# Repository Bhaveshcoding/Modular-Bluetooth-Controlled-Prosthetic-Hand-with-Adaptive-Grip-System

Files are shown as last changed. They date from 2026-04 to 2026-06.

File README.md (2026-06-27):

# Bluetooth-Controlled Prosthetic Hand

---

# NOTE

This project was originally started for Stasis and is now being transferred to Horizons with permission from both organizers.

No funding was received from Stasis, and the project was never approved there. Since Stasis does not require the use of Lapse, I kindly request that project hours be evaluated based on my submitted journal entries.

P.S.-PERMISSION WAS TAKEN FROM @phthallo FOR DOING IT THIS WAY.

Thank you for your consideration.

---

# What It Is

This is a Bluetooth-controlled prosthetic hand that uses servo motors and a simple tendon-driven mechanism to move the fingers. The hand is controlled using an HC-05 Bluetooth module and an Arduino Uno.

I designed all of the CAD myself and built the electronics around it. The goal wasn't to make a medical-grade prosthetic, but to understand how prosthetic hands work and build a working prototype from scratch.

---

## Why I Made This

I've always found prosthetics and assistive technology interesting, so I wanted to try building one myself.

This project gave me a chance to learn more about CAD, mechanical design, electronics, servo control, and how tendon-driven systems work. It also helped me understand some of the challenges involved in designing devices that assist people in everyday tasks.

The project is fairly simple, but it taught me a lot and was a fun way to combine mechanical and electrical design into one build.

---

## CAD

### NOTE

Arm + Electronics Assembly - [(.7z Archive)](CAD/Arm+electronics.7z)

Contains the mandatory **.STEP** file with the complete assembly and integrated electronics. The archive is compressed because of its size.

Google Drive Link:

https://drive.google.com/file/d/1kVEwLl6yhaGHvDUCItGak4jiyQgdJik9/view?usp=sharing

#### STEP Format Files

```text
CAD/3D%20Files%20Robo%20Hand
```

#### F3D & F3Z Format Files

```text
CAD/ROBO%20hand%20files(f3d)
```

## CAD of the Project

#### Full CAD Model

```text
CAD\ROBO hand files(f3d)\hand_3D_RENDER.f3z
```
### Picture of the 3D Printed Model

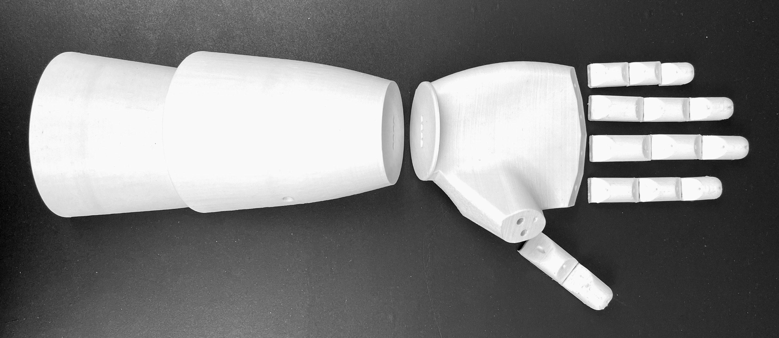
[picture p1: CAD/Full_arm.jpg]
3D printed arm Model


---

### CAD Render

Full CAD Model

---

### Another View

Side View

---

## Design

### Finger Design

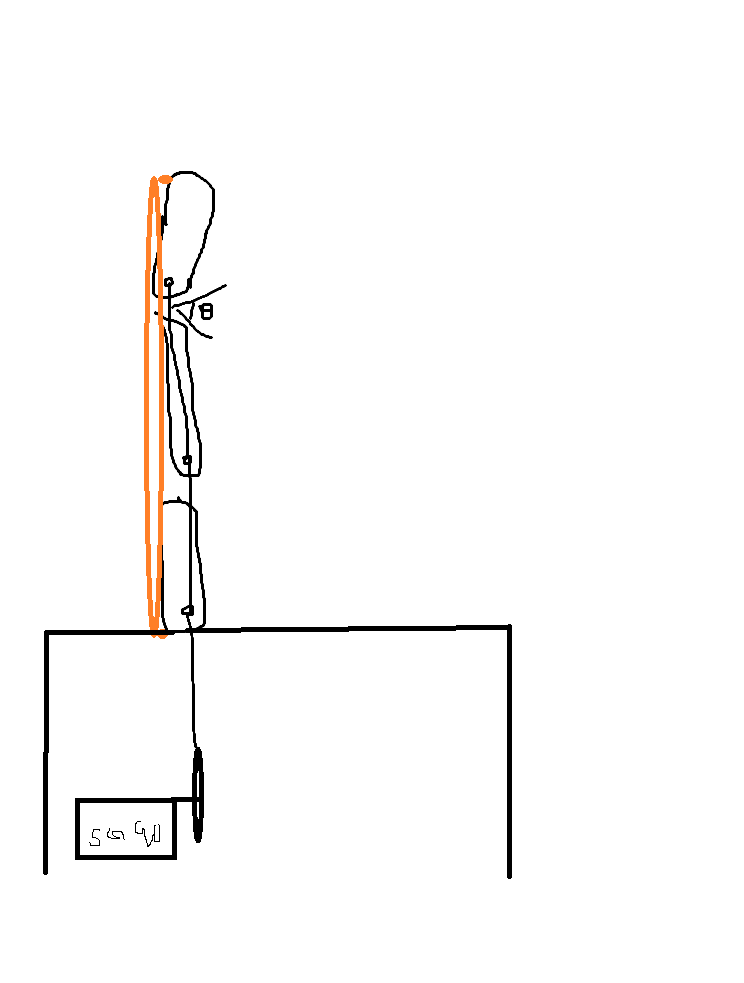
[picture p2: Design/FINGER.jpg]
Finger design


---

### Full Hand Design

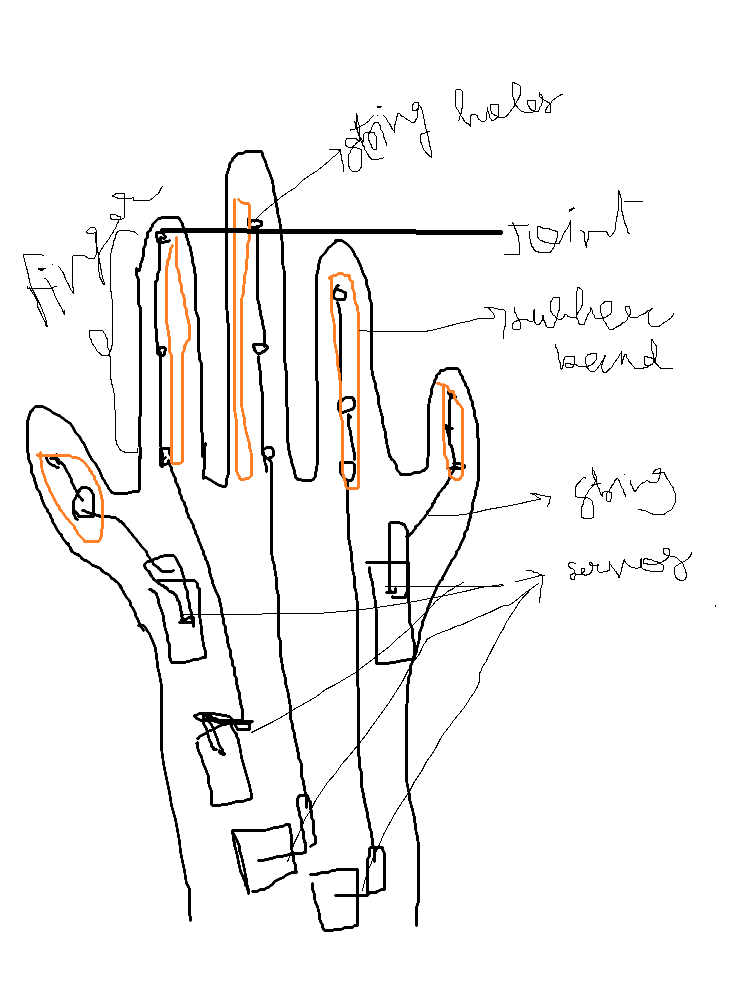
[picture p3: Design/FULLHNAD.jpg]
Full Hand design


---

# Electronics

### TinkerCAD Circuit

https://www.tinkercad.com/things/5ojhNEz72F2-circuit-prosthetichand/editel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

---

### Wiring Diagram

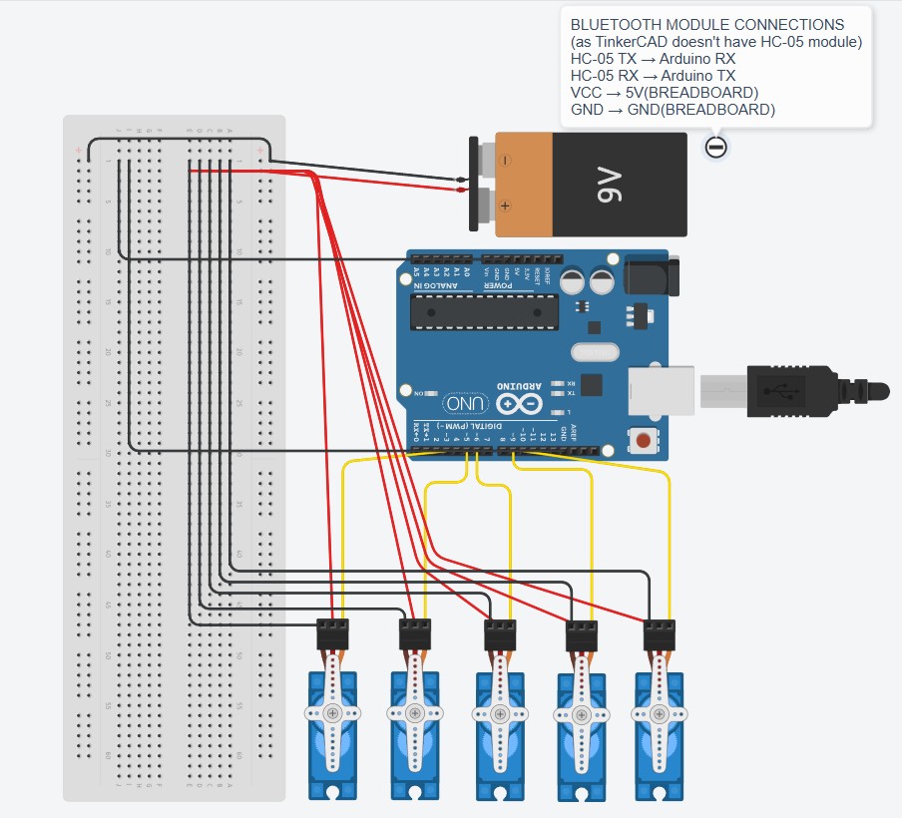
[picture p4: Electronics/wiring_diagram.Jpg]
Wiring Diagram


---

### TinkerCAD Simulation

TinkerCAD Setup

---

I didn't design a PCB for this version of the project. Everything was first prototyped on a breadboard so that testing and changes could be made easily.

---

## Main Components

* Arduino UNO R3
* 5 × SG90/MG90S Servo Motors
* HC-05 Bluetooth Module
* 18650 Battery Pack
* Breadboard
* Jumper Wires
* Nylon Thread (Tendon Mechanism)
* Elastic Thread (Finger Return Mechanism)

---

## Wiring

### Servo Connections

* D3 → Servo 1
* D5 → Servo 2
* D6 → Servo 3
* D9 → Servo 4
* D10 → Servo 5

### Bluetooth Connections

* HC-05 TX → Arduino RX
* HC-05 RX → Arduino TX

### Power

* External battery pack → Servo power
* Common ground shared between all components

---

# Firmware

The firmware allows the hand to perform a few preset grip patterns as well as individual finger control.

Firmware:

[Firmware](Firmware/hand_control.ino)

---

## Grip Modes

* **O** → Open Hand
* **P** → Power Grip
* **I** → Pinch Grip
* **H** → Partial Grip

---

## Individual Finger Control

* **A / a** → Open / Close Finger 1
* **B / b** → Open / Close Finger 2
* **C / c** → Open / Close Finger 3
* **D / d** → Open / Close Finger 4
* **E / e** → Open / Close Finger 5

To make the movement look less jerky, the servos move gradually instead of jumping directly between positions.
# Files Included

* `/CAD` → STEP, F3D, and F3Z CAD files
* `/Firmware` → Arduino source code
* `/Electronics` → Wiring diagrams and TinkerCAD files
* `/Design` → Design images and references
* `BOM.csv` → Complete bill of materials

---

# Bill of Materials (BOM)

| Name | Purpose | Quantity | Total Cost (USD) | Link | Distributor |
| --- | --- | --- | --- | --- | --- |
| Loctite Super Glue Power Gel | Joining 3D-printed parts | 1 | 4.00 | https://www.amazon.in/Loctite-Flexible-Superglue-Non-Drip-Applications/dp/B001C42J9I | AMAZON |
| 3D Printing Material (PLA/ABS) | Printing the hand components | 1 | 4.00 | https://almightyfila.com/product/pla-3d-printing-filament/ | ALMIGHTY FILA |
| Screws & Fasteners | Mechanical assembly | 6 | 0.50 | https://robu.in/product/easymech-ss-304-csk-countersunk-philips-head-m2-5-x-6-mm-bolt-25-pcs-2/ | ROBU |
| Nylon Thread | Tendon mechanism | 1 | 2.00 | https://www.meesho.com/ultra-thin-strong-bright-nylon-high-tensile-strength-thread | MEESHO |
| Elastic Thread 2mm | Finger return mechanism | 1 | 1.00 | https://www.meesho.com/elastic-band-cord-2mm | MEESHO |
| Breadboard | Circuit prototyping | 1 | 0.50 | https://robocraze.com/products/half-breadboard | ROBOCRAZE |
| Jumper Wires (M-M & M-F) | Electrical connections | 20 | 0.50 | https://robocraze.com/products/f2m-jumper-wires-20cm-40pcs | ROBOCRAZE |
| 3.7V 2900mAh 18650 Battery | Power source | 2 | 3.00 | https://robocraze.com/products/3-7v-2900mah-18650-battery | ROBOCRAZE |
| HC-05 Bluetooth Module | Wireless control | 1 | 2.50 | https://robocraze.com/products/hc-05-bluetooth-module | ROBOCRAZE |
| Arduino UNO R3 | Main controller | 1 | 19.00 | https://robocraze.com/products/arduino-uno-original | ROBOCRAZE |
| Servo Motor (SG90/MG90S) | Finger movement | 5 | 5.00 | https://robocraze.com/products/sg90-micro-servo-motor | ROBOCRAZE |

---

# Current Status

At the time of writing this README:

* CAD design is complete.
* Electronics design is complete.
* Firmware has been written.
* Wiring diagrams and documentation are finished.

The next step is full assembly and real-world testing of the hand.

---

# Future Improvements

There are quite a few things I'd like to improve in future versions:

* Assemble and test the full system
* Improve tendon routing and reduce friction
* Add force feedback or grip sensing
* Design a custom PCB instead of using a breadboard
* Make the hand more durable and compact
* Experiment with additional grip patterns

---

# AI-Generated Content Notice

AI tools were used to assist with parts of the documentation and writing process. All design work, CAD models, electronics, firmware, and project development were completed by me.

---

# Final Thoughts

This project started as a way for me to learn more about prosthetics, CAD, and electronics.

While it's still a prototype, I learned a lot about designing mechanical systems, working with servos, routing tendon mechanisms, and integrating hardware with software. Building everything from the CAD model to the control system gave me a much better understanding of how prosthetic devices work.

I hope this repository is useful to anyone interested in robotics, assistive technology, or building their own prosthetic hand projects.

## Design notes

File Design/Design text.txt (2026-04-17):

Modular Bluetooth-Controlled Prosthetic Hand with Adaptive Grip System

MECHANICAL-
	- 5 Fingers
		-3 segment pull
	- String based pulling
		-nylon rope
		-fishing rope
	-Rubber Band return

ELECTRONICS-
	-Arduino UNO R3
	-5 servo motors
		-1servo/finger
	-Bluetooth Control

CONTROLS-
	-Predefined grip modes(using Blue tooth)
		-OPEN
		-CLOSE
		-SEMIOPEN
		-INDIVIDUAL FINGER MOVEMENT

CONTROL METHODS-
	-Bluetooth

DESIGN-
	-3D printed parts

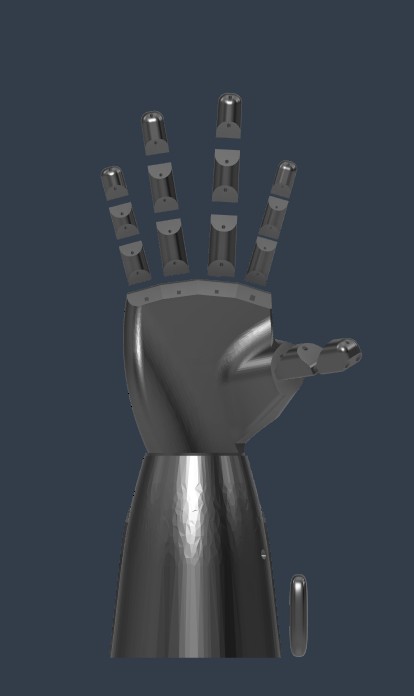
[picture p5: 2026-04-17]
CAD/3d_RENDER(front).jpg

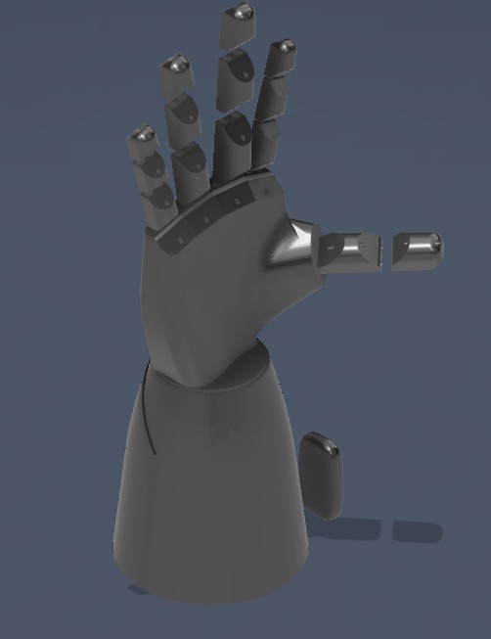
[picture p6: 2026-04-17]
CAD/3d_RENDER(home).jpg

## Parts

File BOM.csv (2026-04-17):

Name | Purpose | Quantity | Total Cost (USD) | Link | Distributor
Loctite Super Glue Power Gel | Sticking 3d printed parts | 1 | 4.00 | https://www.amazon.in/Loctite-Flexible-Superglue-Non-Drip-Applications/dp/B001C42J9I | AMAZON
3D Printing Material (PLA/ABS) | Material for printing parts,PLA/ABS filament | 1 | 4.00 | https://almightyfila.com/product/pla-3d-printing-filament/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 | ALMIGHTY FILA
Screws & Fasteners | Assembly components,M2/M3 screws | 6 | 0.50 | https://robu.in/product/easymech-ss-304-csk-countersunk-philips-head-m2-5-x-6-mm-bolt-25-pcs-2/ | ROBU
Nylon thread | Tendon Mechanism | 1 | 2.00 | https://www.meesho.com/ultra-thin-strong-bright-nylon-high-tensile-strength-bright-2-ply-thread-for-beading-jewellery-and-crafts-making-nylon-2-pcs-black-5002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 | MEESHO
Elastic Thread 2mm | High strength elastic For Tendon Pullback | 1 | 1.00 | https://www.meesho.com/elastic-band-cord-2mm-10-meter-white-for-bracelet-hair-ribbon-craft-creation/p/ajn526 | MEESHO
Breadboard | Prototyping board,Standard 400 points | 1 | 0.50 | https://robocraze.com/products/half-breadboard?_pos=1&_sid=c3c51781a&_ss=r | ROBOCRAZE
Jumper Wires(M-M & M-F) | Electrical connections | 20 | 0.50 | https://robocraze.com/products/f2m-jumper-wires-20cm-40pcs?_pos=1&_sid=5ad6b34f4&_ss=r | ROBOCRAZE
3.7V 2900mAh 18650 Battery | Power supply for system | 2 | 3.00 | https://robocraze.com/products/3-7v-2900mah-18650-battery?_pos=14&_sid=14c477bae&_ss=r | ROBOCRAZE
HC-05 Bluetooth Module | Wireless communication module | 1 | 2.50 | https://robocraze.com/products/hc-05-bluetooth-module?variant=40193264189593&country=IN&currency=INR | ROBOCRAZE
Arduino UNO R3 | Microcontroller board | 1 | 19.00 | https://robocraze.com/products/arduino-uno-original?variant=40192399442073&country=IN&currency=INR | ROBOCRAZE
Servo Motor (SG90/MG90S) | Micro Servo for finger actuation,180° rotation | 5 | 5.00 | https://robocraze.com/products/sg90-micro-servo-motor?variant=40192525238425&country=IN&currency=INR | ROBOCRAZE

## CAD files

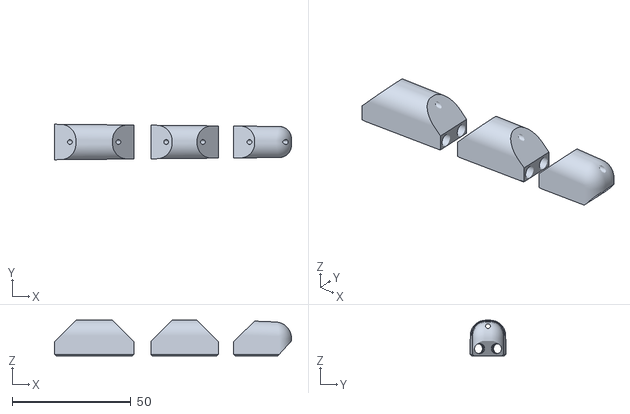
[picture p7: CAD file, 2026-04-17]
CAD/3D Files Robo Hand/Finger_Middle.stl
100.0 x 15.0 x 15.0

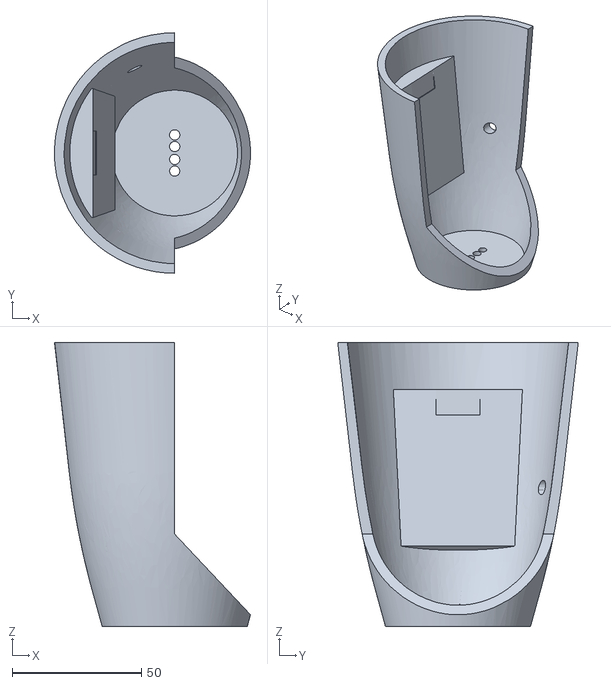
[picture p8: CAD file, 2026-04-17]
CAD/3D Files Robo Hand/Arm.stl
75.9 x 93.1 x 109.9

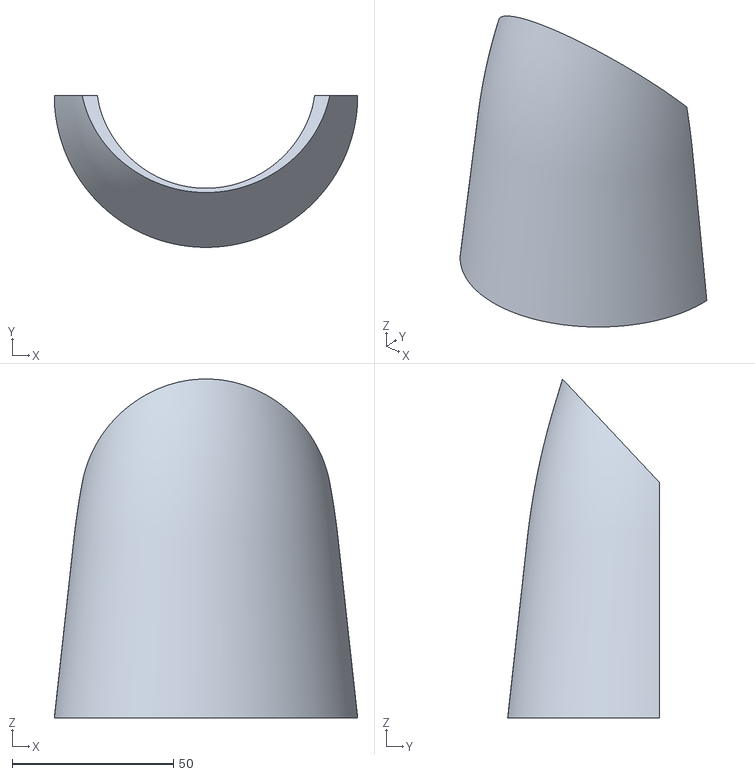
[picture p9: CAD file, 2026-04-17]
CAD/3D Files Robo Hand/Arm_Cover.stl
94.0 x 47.0 x 105.0

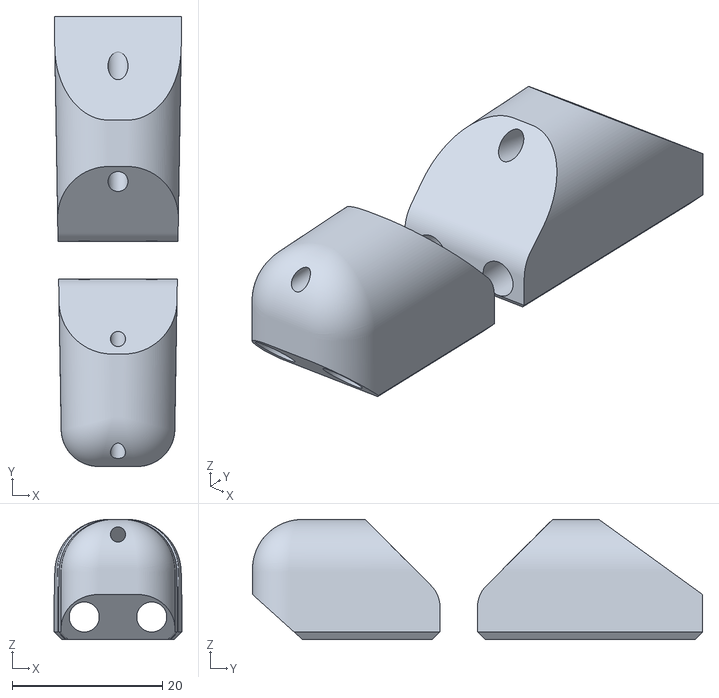
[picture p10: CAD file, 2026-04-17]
CAD/3D Files Robo Hand/Finger_Thumb.stl
17.0 x 60.0 x 16.0

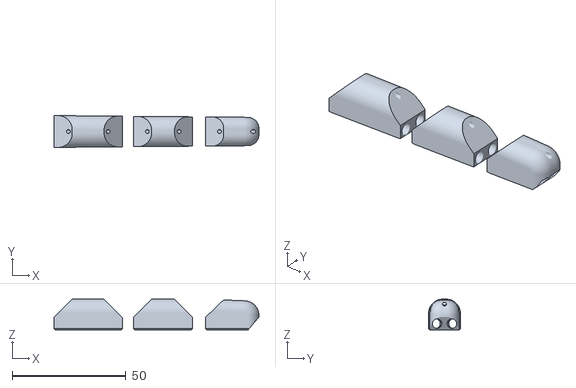
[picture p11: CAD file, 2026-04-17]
CAD/3D Files Robo Hand/Finger_Ring.stl
90.0 x 14.0 x 13.5

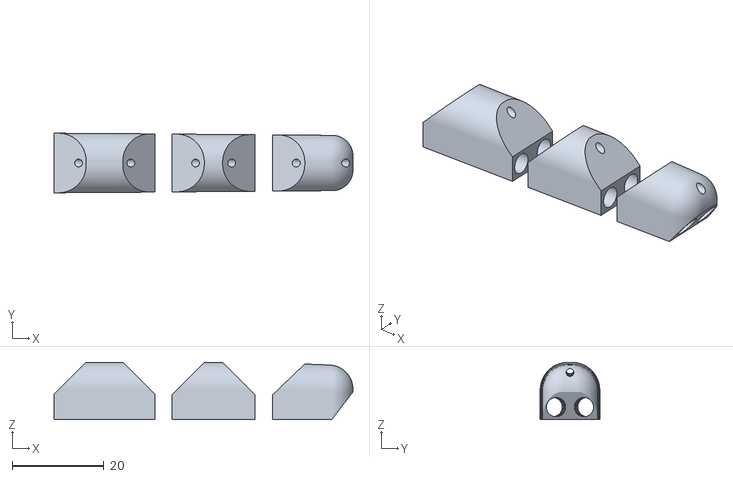
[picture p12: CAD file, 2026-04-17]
CAD/3D Files Robo Hand/Finger_Pinky.stl
65.2 x 13.0 x 12.5

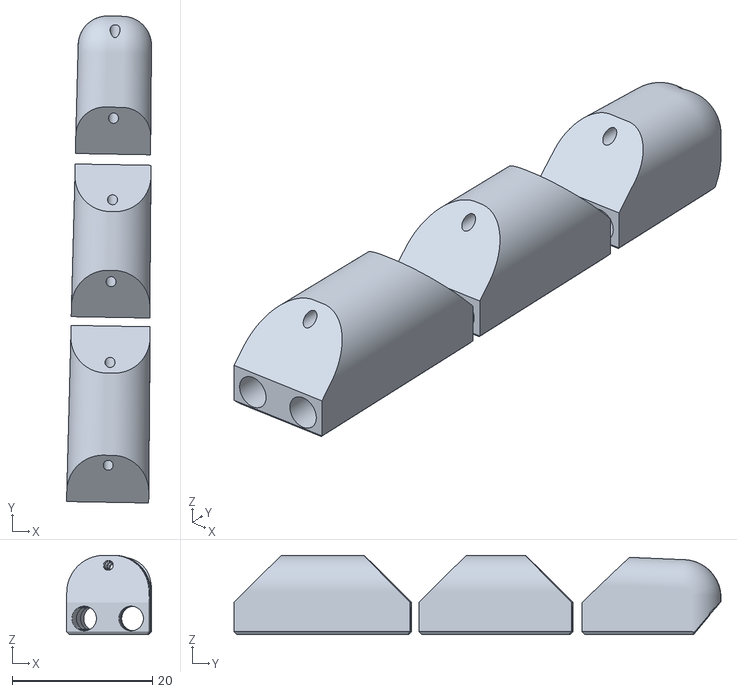
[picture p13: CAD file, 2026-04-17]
CAD/3D Files Robo Hand/Finger_Index.stl
12.1 x 69.4 x 11.3

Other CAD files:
CAD/ROBO hand files(f3d)/Arm.f3d
CAD/ROBO hand files(f3d)/Arm_Cover.f3d
CAD/ROBO hand files(f3d)/Finger_Index.f3d
CAD/ROBO hand files(f3d)/Finger_Middle.f3d
CAD/ROBO hand files(f3d)/Finger_Pinky.f3d
CAD/ROBO hand files(f3d)/Finger_Ring.f3d
CAD/ROBO hand files(f3d)/Finger_Thumb.f3d
CAD/ROBO hand files(f3d)/hand_3D_RENDER.f3z
CAD/ROBO hand files(f3d)/prosthetic_hand.f3z

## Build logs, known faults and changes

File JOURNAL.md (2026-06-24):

<!--
  This journal is auto generated by Stasis.
-->
# Total time spend
## STASIS HRS-23.1 hrs
## HACKATIME HRS-3.3
# TOTAL=26.4 HRS

# NOTE

This project was originally started for Stasis and is now being transferred to Horizons with permission from both organizers.

No funding was received from Stasis, and the project was never approved there. Since Stasis does not require the use of Lapse, I kindly request that project hours be evaluated based on my submitted journal entries.

Thank you for your consideration.

---
# 4/15/2026 4 PM - Electronics System Mapping and Firmware Development (DAY-7)

_Time spent: 3.5h_

### **Electronics System Mapping and Firmware Development (DAY-7)**

---

### **Goals**

* Use TinkerCAD to make a full wiring diagram for electronics
* Map the connections for five servos and an Arduino control system* Put the HC-05 Bluetooth module together in your mind
* Make firmware that lets you control multiple grips and move each finger separately

---

### **Work Done**

During this session, I worked on the electronics architecture and control logic for the prosthetic hand. I made a TinkerCAD model with an Arduino Uno, a breadboard, and five servo motors. I assigned each servo to a different PWM pin. I made sure that the power was distributed correctly by using an external supply and that all the parts shared a common ground.

I wrote down the connections for the HC-05 Bluetooth module separately and added its logic to the firmware because TinkerCAD doesn't support it. Then I wrote Arduino code to let the device use different grip modes, like power grip, pinch grip, and partial grip. I also set up a structured command system (A–E for open, a–e for close) that lets me control each finger separately. Incremental servo movement made it possible to move smoothly.

---

### **Challenges**

Managing multiple servo connections initially led to a cluttered layout, requiring several iterations to organize clearly. Understanding proper power distribution for multiple servos was also important. Another challenge was representing Bluetooth functionality without simulation support, which I solved through documentation and code integration.

---

### **Outcome**

I initially had a messy layout while working on multiple servo connections and had to go through a few iterations to get it clean and organized. Understanding how to properly power distribution for multiple servos was also important. Another challenge was to simulate bluetooth functionality which has no support for simulation. I solved this by documenting and integrating code.

---

### **Next Steps**

* Final BOM with all components
* Merge electronics with CAD assembly* Full README documentation with wiring and firmware explanation

---

### **Images**

#### 1. Electronics wiring diagram (TinkerCAD)
       


#### 2. Firmware code snapshot
   




---
 ### **TinkerCAD LINK**

https://www.tinkercad.com/things/5ojhNEz72F2-circuit-prosthetichand/editel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






# 4/14/2026 12 PM - Arm Module with Servo Mount and Protective Cover Design

_Time spent: 3h_

##  Arm Module with Serbo Mount and Protective Cover Design(DAY-6)
---

### Goals
- Design forearm structure for electronics and servos  
- Create a stable servo mounting area  
- Create an outer shell for protection and structure  

---

### Work Done
In this session, I made the arm module that will hold the electronics and serve as the base of the prosthetic system. I made a hollow cylinder and shaped the inside so that parts would fit. I put an angled block inside that would be used to mount the servo. I also made a separate outer cover that fits around the arm to make sure it is properly aligned and enclosed.

---

### Challenges
One big problem was working in mesh format, which made it hard to make precise changes. It took several adjustments to get the servo mounting space to fit properly inside the curved structure. I also had to make sure that the cover fits snugly without any gaps and is thick enough to be strong.

---

### Outcome
Made a working arm structure with room for a servo and a matching protective cover.

---

### Next Steps
- Add paths for tendons to go from the arm to the fingers  
- Make servo positioning more accurate by combining it  
- Start planning where to put the electronics  
---

### Images
#### 1)Arm and Cover showing symmetry


--- 
#### 2)Arm Cover


---

#### 3)Arm with servo mouting station


---





# 4/13/2026 6 PM - Palm Structure Finalization (Mesh Optimization)(DAY-5)

_Time spent: 3.5h_

## Palm Structure Alignment & Mesh Finalization(DAY-5)

### Goals
- Finish the shape of the base and palm  
- Check that the holes for the fingers are in the right place  
- Check that the mesh is clean and can be printed on  

---

### What I Did
I worked on making the palm structure of the prosthetic hand better during this session. The main goal was to improve the overall shape and ensure that the areas where the fingers connect lined up with the existing finger models. I changed the sizes and positions so that the holes and joints fit together correctly for assembly. I also looked at the mesh quality (about 35,000 triangles) and made sure it was good enough to print without adding any extra difficulty. I also looked at the inside space to see if it would work for adding servos and wiring in the future.

---

### Challenges 
During this session, I worked on making the palm of the prosthetic hand better. The main goal was to improve the overall shape and make sure that the finger connections lined up with the existing finger models. I changed the sizes and positions so that the holes and joints fit together properly when putting them together. I also checked the mesh quality (about 35,000 triangles) to make sure it was good enough to print without making things harder. I also checked the inside space to see if it would be good for adding servos and wiring in the future. 

---

### Outcome
A palm structure that is clean and well-aligned, ready to be integrated and printed. 

---

### Next Steps
- Make the electronics base fit inside the palm  
- Make room for servo mounts  
- Make a cover for the outside that protects it  

---

### Images











# 4/13/2026 1 PM - Full Finger Modeling + Return Mechanism Planning(DAY-4)

_Time spent: 4.25h_

## Full Finger Modeling + Return Mechanism Planning (DAY-4)

### Goal 
Finish modeling all five fingers so that they all have the same proportions, and then come up with a reliable way for the fingers to extend smoothly. 

--- 

### What Did You Work On? 
I finished modeling all five fingers during this session, using the final single-finger design as a guide. I copied the base model and changed each finger—the thumb, index, middle, ring, and pinky—to make sure the proportions and scaling were correct. I made sure that each part (proximal, middle, and distal) tapered smoothly from the base to the tip. I didn't want any bulky or uneven shapes. 

I made sure that all of the fingers worked the same way mechanically. I made sure that the hinges, pin holes, and tendon channels were all in the right places so that all the fingers work the same way and can be easily controlled when they are put together. 

I also made the outside shape better to make it look better overall. Some parts looked blocky or like they had facets, so I changed the sizes and transitions to make the fingers look more natural and fit together better. 

I also made the final decision about the return mechanism by choosing elastic thread over rubber bands. This meant making sure that the design had the right routing, tensioning, and durability. 

--- 

### Challenges 
- Making sure that all of the fingers are the same size 
- Fixing small visual problems that come up when dimensions change slightly 
- Keeping the structure strong while making it look less blocky 
- Picking and planning a reliable way to get things back 

--- 

### Next Steps 
- Make the palm big enough to hold all five fingers 
- Make a place for the servo housing and mounting slots in the base 
- Make a cover that will protect the wiring and electronics. 
---
### Images

1)Index Finger



2)Middle Finger



3)Ring Finger



4)Pinky Finger



5)Thumb Finger



---







# 4/11/2026 6 PM - Base Finger Structure Modeling (Rectangular Segments)

_Time spent: 1.75h_

##  Base Finger Structure Modeling (Rectangular Segments)(DAY-3)

### Goal  
Design and model the basic rectangular shape of a single robotic finger, making sure that the proportions are right, the segments are divided correctly, and the joints and tendons can move freely.

---

### Work Done  
I started with simple rectangular profiles to build the base shape of the finger in this session. Then I moved on to more complicated shaping. To keep things consistent and scalable, I made three separate segments: proximal, middle, and distal, each with its own size.

I made each part look like a solid block by using sketches and extrusions, making sure they were all lined up along one axis. Then I added hinge connection areas between the segments and carefully placed tab-like extensions to make it possible for the joints to rotate.

I also added internal cutouts and channels for routing tendons, making sure they were in the center and didn't affect the structural integrity of the segments. We added mounting holes for pins, making sure they were evenly spaced and symmetrical so that the joint could move properly.

I kept the parts the same thickness and spaced them out evenly throughout the process to avoid problems with assembly later on.

---

### Issues Faced  
- At first, it was hard to keep all three segments in line with each other.  
- Hard to put hinge tabs in the right place evenly  
- Had to change the sizes of the parts several times to make sure they fit together correctly  
- Making sure there is enough space for joints without making them too loose  

---

### Fixes  
- Used reference lines and limits to keep everything in line  
- Made sure that the dimensions were the same across all segments for consistency  - Made the holes a little bigger so that the pins could move smoothly  
- Improved the space between the hinge parts to find a good balance between fit and movement  

---

### Result  
Used rectangular segments to make a clean and structurally sound base model of the finger. The model is ready for more work and shaping in later stages because all of the parts are in the right place.

---

### Next Step  
Refine the finger's outer shape to make it look more realistic and comfortable, while keeping the internal mechanical structure intact.

---

## Images  

### 1) Base Rectangular Finger Segments  



### 2) Hinge and Internal Channel Layout  



---




# 4/9/2026 5 PM - Finger Actuation Setup and Basic Movement(DAY-2)

_Time spent: 2.25h_

## Finger Actuation Setup and Basic Movement

### Goal

Use Arduino to make a single tendon-driven robotic finger that can bend and return in a controlled way.

---

### Work Done

* Made a three-part finger out of cardboard for quick prototyping
* Made hinge joints with toothpicks and wire so they could turn smoothly
* Used thread to connect the tendon mechanism to the finger segments
* Added a rubber band so that the fingers could automatically return (extend)
* Attached a servo motor to a stable base structure
* Attached tendon string to servo horn to make it work
* Hooked up the servo to the Arduino Uno (with a signal pin and an external power supply)
* Uploaded and tested basic code for controlling a servo to open and close
* Adjusted the angles of the servos and the tension of the strings to get a wider range of motion.

---

### Issues Faced

* Finger was too stiff at first because the joints were too tight and there was too much friction.
* Routing the tendon made the bending uneven across segments
* The servo's movement was jerky because the angle mapping was wrong
* During testing, the string slipped off the servo horn
* The return mechanism (rubber band) was either too weak or too strong.

---

### Fixes

* Made the holes in the joints a little bigger to lower friction and make things smoother.
* Changed the path of the tendon to make sure that all segments bend the same way
* Set the servo angles so that they work right for opening and closing.
* Tied the tendon down tightly to the servo horn with tighter knots.
* Tried out different levels of tension on the rubber bands to keep the movement even

---

### Result

Used a servo motor to control finger movement successfully. When you press the button, the finger bends smoothly and goes back to where it was before. This proves that the main mechanical and actuation system can be used on all five fingers.
---

### Next Step

Copy the design of the working finger for all of the fingers, and then start putting multiple servos into a single palm structure.
---

## Images

### 1) Finger Mechanism Build



### 2) Servo Integration and Movement Test



---




# 4/8/2026 12 PM - System Design Lock & Architecture Planning

_Time spent: 1.5h_

# System Design Lock & Architecture Planning(DAY-1)

## Goals

Set up a clear and workable system architecture.
Choose between Bluetooth control, which is easier, and the more complicated MPU glove.
Decide how many servos you need and how to control your fingers.
Choose between rapid prototyping and 3D printing for prototyping.
##

## What I Worked On

Before I started building, I made sure to plan and lock the whole system. I divided the project into four main parts: structure (the palm and mounting), electronics (the Arduino and servos), control (Bluetooth commands), and mechanics (the tendon-driven fingers).

At first, I thought about adding a glove with an MPU for gesture control. But after thinking about how hard it would be to put into place and how little time I had, I decided to get rid of it and work on a Bluetooth-controlled system that was more reliable.

I finished the design by adding 5 servos (one for each finger) for independent control, as well as preset grip modes (OPEN, HALF, CLOSE) and Bluetooth-based manual micro-adjustment.

I also looked at different ways to make things and decided to start with cardboard for the prototype and then improve it later with 3D printing if necessary.
## 
##  Challenges / Rabbit Holes
Risk of overengineering: Spent time thinking about MPU-based control, which made things more complicated than they needed to be.
Not being able to decide on a design: Picking between 3 and 5 servos meant weighing ease of use against usefulness.
Choice of fabrication: 3D printing seemed perfect, but the speed of iteration was a problem.
## 
## Outcomes
Final system architecture is locked
Five independent servo controls were chosen.
Took out MPU-based control to lower risk
picked a tendon-driven mechanism
Choosing cardboard prototyping and then 3D printing later
Ready to start building in the next session
##
## Images
### 1)Finger only design
FINGER
##
### 2)Full Hand
FULLHNAD
##




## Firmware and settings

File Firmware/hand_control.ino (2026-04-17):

#include <Servo.h>

// Servo objects
Servo s1, s2, s3, s4, s5;

// Current positions
int p1 = 10, p2 = 10, p3 = 10, p4 = 10, p5 = 10;

// Limits
int openPos = 10;
int closePos = 90;

// Smooth move
void moveServo(Servo &servo, int &currentPos, int target) {
    int step = (target > currentPos) ? 1 : -1;

    while (currentPos != target) {
    currentPos += step;
    servo.write(currentPos);
    delay(10);
    }
}

// Move all
void moveAll(int t1, int t2, int t3, int t4, int t5) {
    moveServo(s1, p1, t1);
    moveServo(s2, p2, t2);
    moveServo(s3, p3, t3);
    moveServo(s4, p4, t4);
    moveServo(s5, p5, t5);
}

// Grip Modes
void openHand() {
    moveAll(openPos, openPos, openPos, openPos, openPos);
}

void powerGrip() {
    moveAll(closePos, closePos, closePos, closePos, closePos);
}

void pinchGrip() {
    moveAll(closePos, closePos, openPos, openPos, openPos);
}

void partialGrip() {
    int mid = (openPos + closePos) / 2;
    moveAll(mid, mid, mid, mid, mid);
}

// Individual control
void openFinger(int id) {
    switch (id) {
    case 1: moveServo(s1, p1, openPos); break;
    case 2: moveServo(s2, p2, openPos); break;
    case 3: moveServo(s3, p3, openPos); break;
    case 4: moveServo(s4, p4, openPos); break;
    case 5: moveServo(s5, p5, openPos); break;
    }
}

void closeFinger(int id) {
    switch (id) {
    case 1: moveServo(s1, p1, closePos); break;
    case 2: moveServo(s2, p2, closePos); break;
    case 3: moveServo(s3, p3, closePos); break;
    case 4: moveServo(s4, p4, closePos); break;
    case 5: moveServo(s5, p5, closePos); break;
    }
}

void setup() {
    Serial.begin(9600);

    s1.attach(3);
    s2.attach(5);
    s3.attach(6);
    s4.attach(9);
    s5.attach(10);

    openHand();
}

void loop() {
    if (Serial.available()) {
    char cmd = Serial.read();

    switch (cmd) {

      // Grip modes
        case 'O': openHand(); break;
        case 'P': powerGrip(); break;
        case 'I': pinchGrip(); break;
        case 'H': partialGrip(); break;

      // Individual OPEN (A–E)
        case 'A': openFinger(1); break;
        case 'B': openFinger(2); break;
        case 'C': openFinger(3); break;
        case 'D': openFinger(4); break;
        case 'E': openFinger(5); break;

      // Individual CLOSE (a–e)
        case 'a': closeFinger(1); break;
        case 'b': closeFinger(2); break;
        case 'c': closeFinger(3); break;
        case 'd': closeFinger(4); break;
        case 'e': closeFinger(5); break;
    }
    }
}

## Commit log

2026-04-17 Initial upload through VS code
    [Arm+electronics.step, Arm.f3d, Arm.stl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]
2026-04-17 Rename BOM .csv to BOM.csv
    [BOM.csv]
2026-04-17 Update README with CAD assembly note
    Added a note about the CAD and electronics assembly archive in the README.
